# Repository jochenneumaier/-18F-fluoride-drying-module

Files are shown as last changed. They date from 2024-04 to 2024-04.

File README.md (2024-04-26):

# 18F-fluoride-drying-module
Automated drying module for [18F]fluoride

One of the key strategies for radiochemical research facilities is the automation of synthesis processes. Unnecessary manual operations increase the radiation exposure of personnel, while simultaneously threatening the reliability of syntheses. We have previously reported an affordable open-source system comprising 3D-printed continuous flow reactors, a custom syringe pump, and a pressure regulator that can be used to perform radiofluorinations. In this paper, we address additional essential processes which are needed for radiotracer development and synthesis, with the aim of making laboratory work safer and research more efficient. We have designed and evaluated a fully automated system for rapidly and effectively processing and drying aqueous [18F]fluoride that can be directly connected to the cyclotron. This process relies on triflyl fluoride gas generation and allows nucleophilic [18F]fluoride to be prepared safely in a hotcell within 10 minutes and an activity recovery of 91.7 ± 1.6% (n=5). Owing to the need for convenient radiofluorinated prosthetic ligands, we have adapted our continuous flow system to produce [18F]fluoroethyl tosylate (FEOTs) and [18F]fluoroethyl triflate (FEOTf), prosthetic groups that are widely used for late-stage fluoroethylation of PET tracers. The processes as well as the radiolabeling of different groups are compared and comprehensively discussed. Having a method providing [18F]fluoroethyl tosylate (FEOTs) as well as [18F]fluoroethyl triflate (FEOTf) quickly and highly efficiently is beneficial for radiochemical research. 

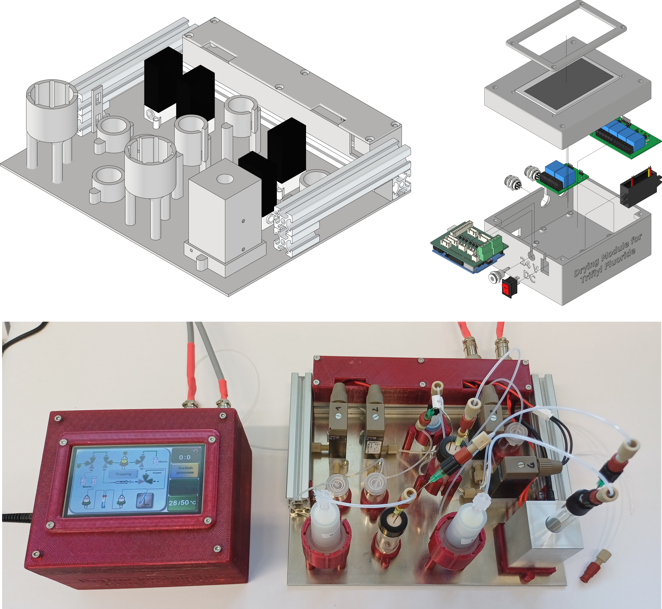
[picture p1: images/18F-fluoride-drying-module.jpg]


The work was published in the Journal of Labelled Compounds and Radiopharmaceuticals:

Open-source flow setup for rapid and efficient [18F]fluoride drying for automation of PET tracer syntheses, F. Menzel, J. Cotton, T. Ziegler, A. Maurer, J. M. Neumaier, J. Label. Compd. Radiopharm. 2023, 1-19, 

https://doi.org/10.1002/jlcr.4080

https://analyticalsciencejournals.onlinelibrary.wiley.com/doi/epdf/10.1002/jlcr.4080

A detailed assembly instructions can also be downloaded here:

https://analyticalsciencejournals.onlinelibrary.wiley.com/action/downloadSupplement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

All CAD and stl files as well as the Arduino and Nextion program codes can be downloaded here:

https://analyticalsciencejournals.onlinelibrary.wiley.com/action/downloadSupplement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

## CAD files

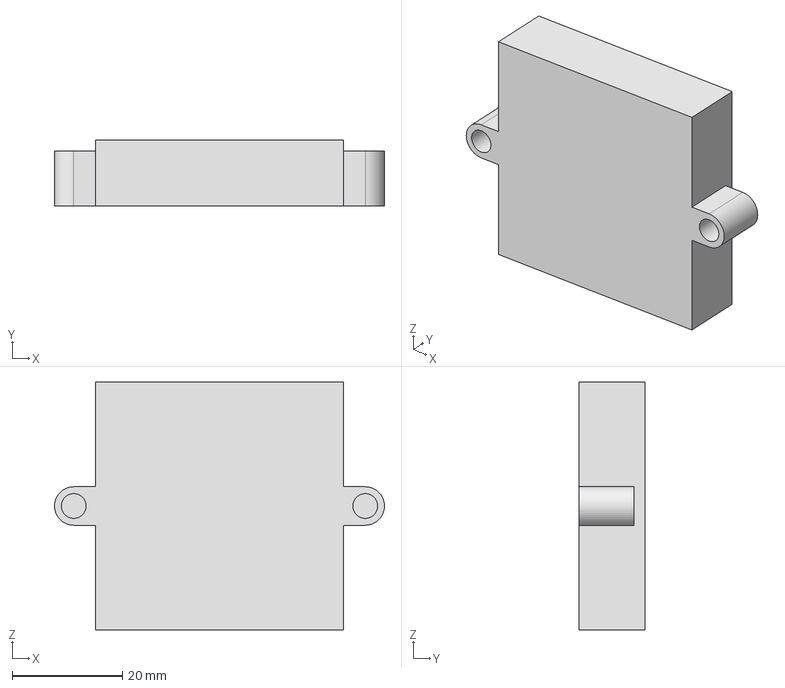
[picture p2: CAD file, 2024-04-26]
CAD files/5 - Holder heating block.stp
60.0 x 12.0 x 45.0 mm

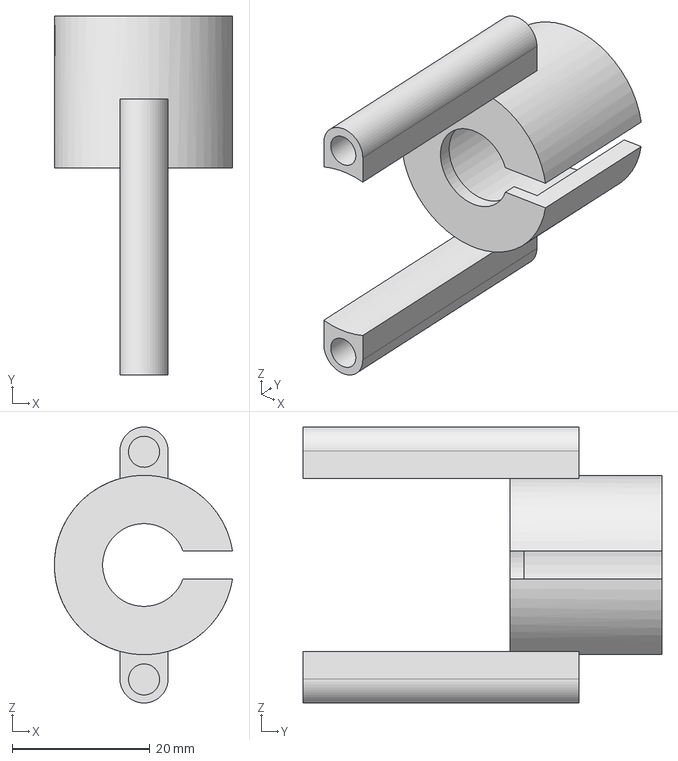
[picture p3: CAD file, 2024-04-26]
CAD files/1 - Holder QMA.stp
25.8 x 52.0 x 40.0 mm

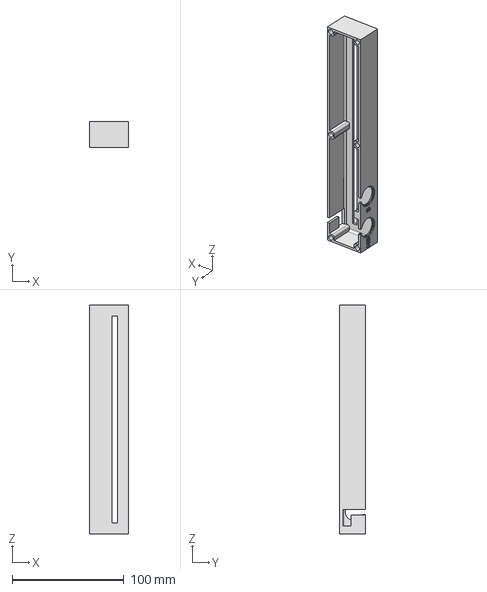
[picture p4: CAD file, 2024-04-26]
CAD files/6 - Cable box.stp
35.0 x 23.0 x 205.0 mm

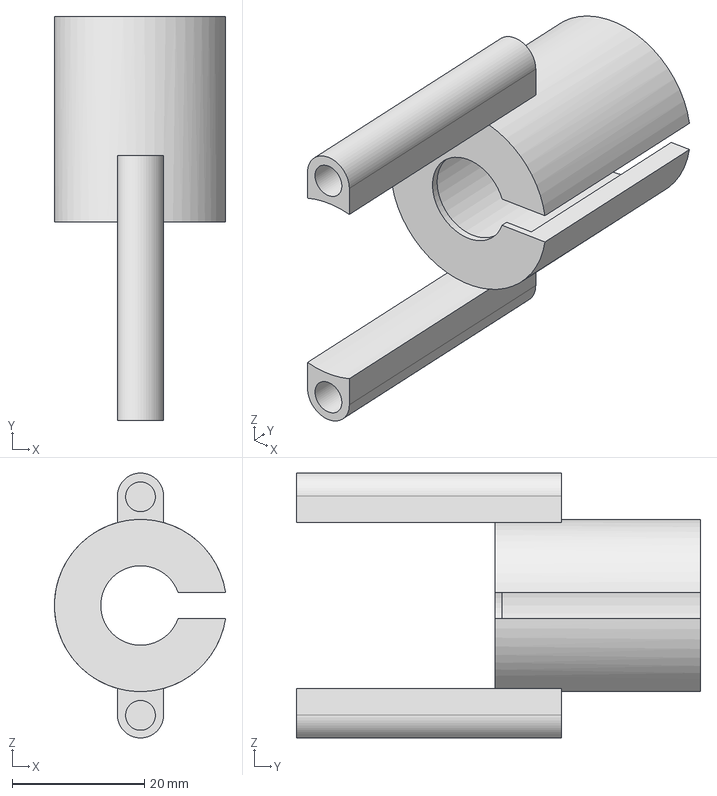
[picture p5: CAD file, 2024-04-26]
CAD files/2 - Holder v-vial, high.stp
25.8 x 61.0 x 40.0 mm

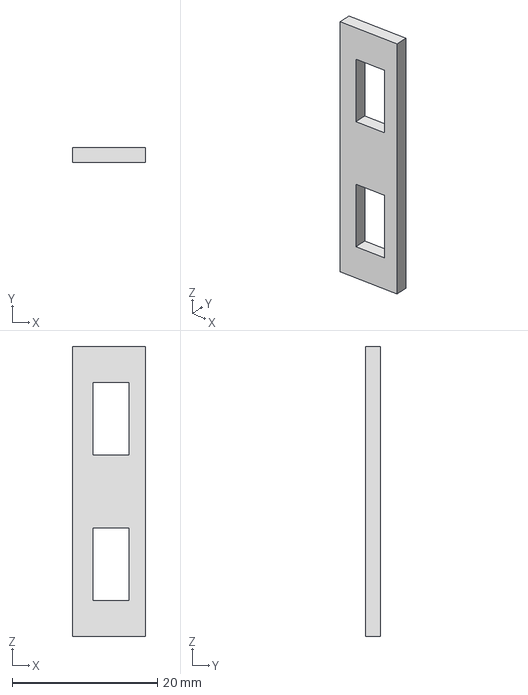
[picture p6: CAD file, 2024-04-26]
CAD files/8 - Profile connector straight.stp
10.0 x 2.00 x 40.0 mm

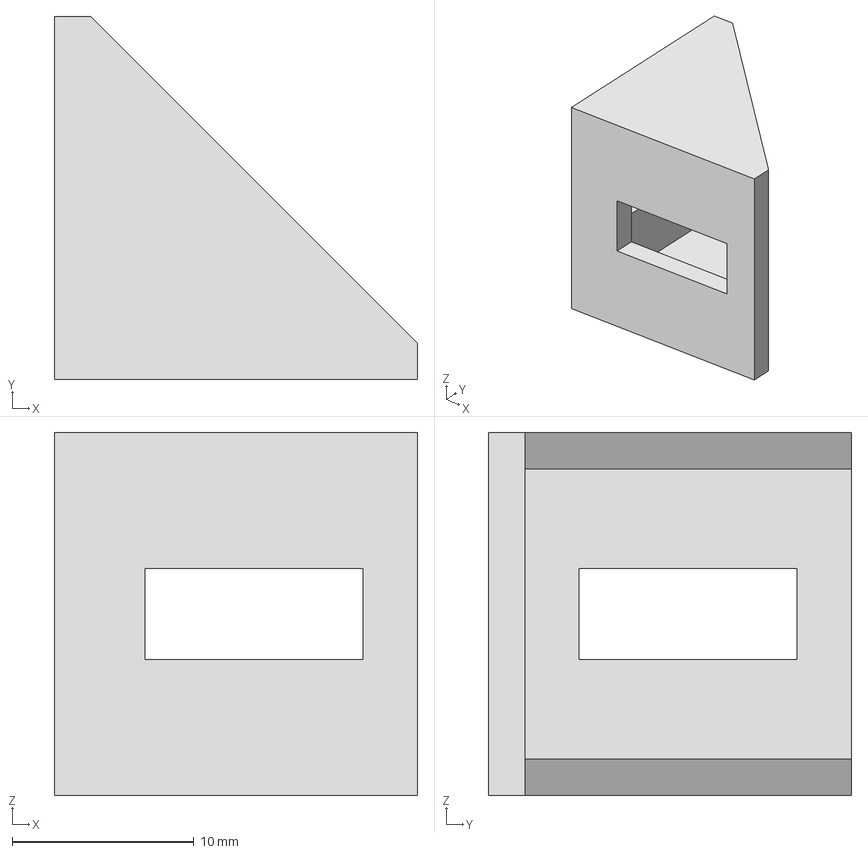
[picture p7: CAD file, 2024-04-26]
CAD files/9 - Profile connector 90 degree.stp
20.0 x 20.0 x 20.0 mm

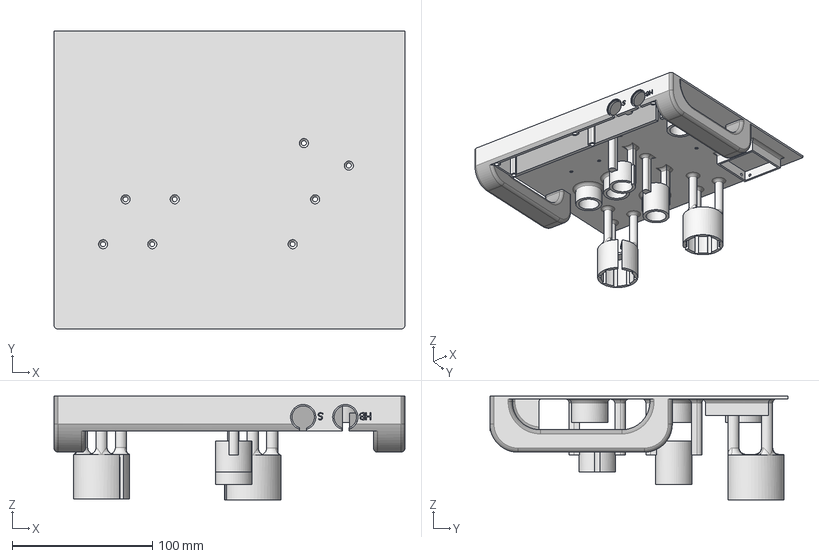
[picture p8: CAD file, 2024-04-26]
CAD files/50 - All-in-one base plate.stp
250.0 x 212.5 x 74.0 mm

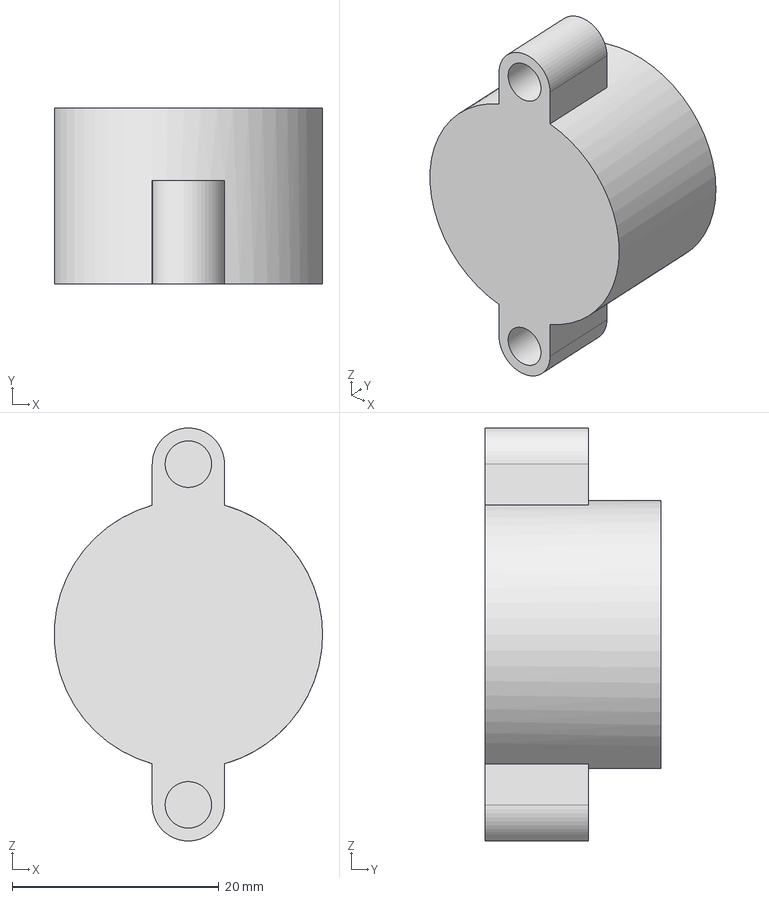
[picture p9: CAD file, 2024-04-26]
CAD files/3 - Holder waste, v-vial low.stp
26.0 x 17.0 x 40.0 mm

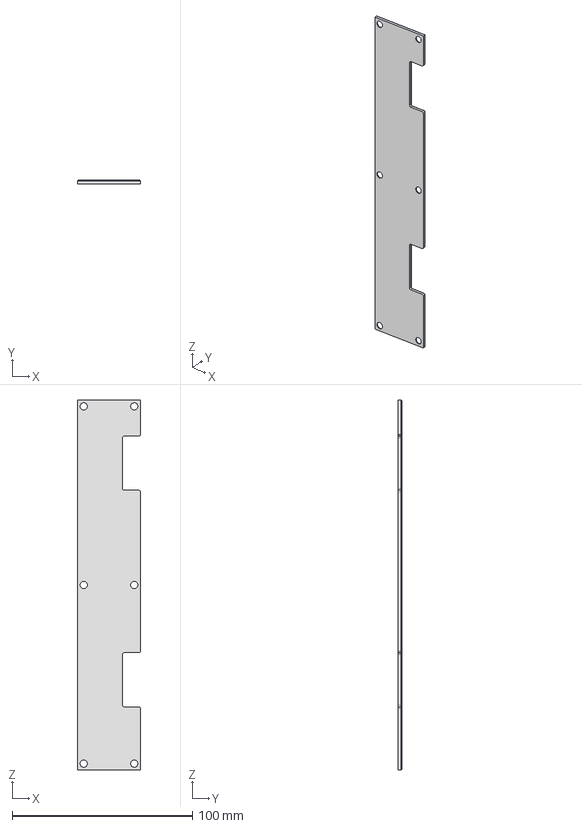
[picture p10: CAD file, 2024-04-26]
CAD files/7 - Cable box lid.stp
35.0 x 2.00 x 205.0 mm

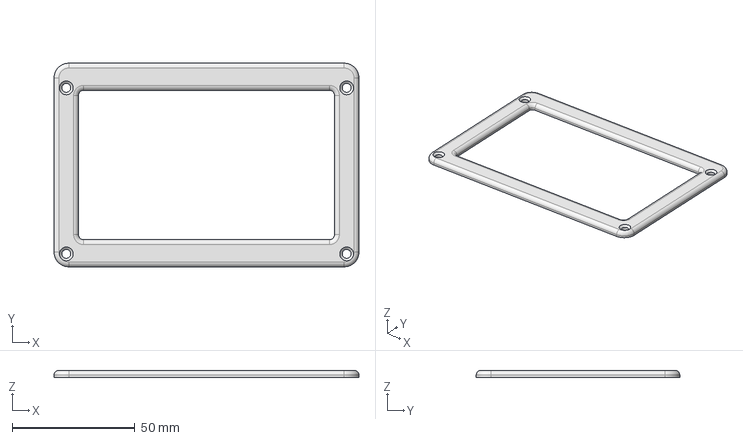
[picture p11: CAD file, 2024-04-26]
CAD files/17 - Display frame.stp
124.0 x 82.8 x 3.00 mm

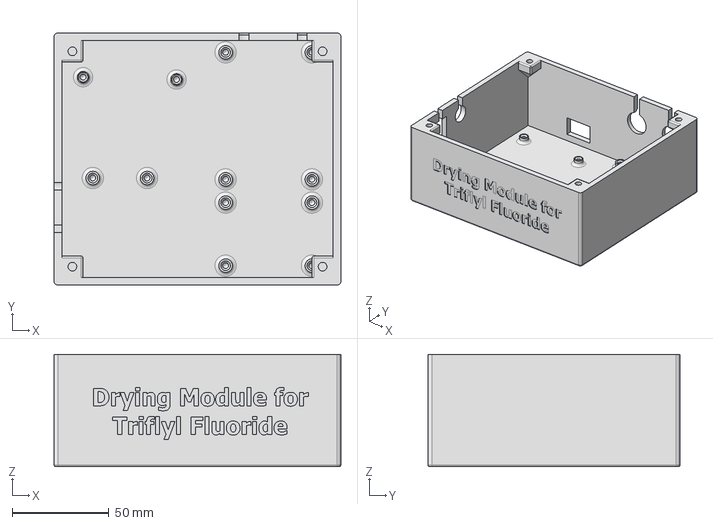
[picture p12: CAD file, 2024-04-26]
CAD files/15 - Case control unit.stp
148.0 x 130.0 x 58.0 mm

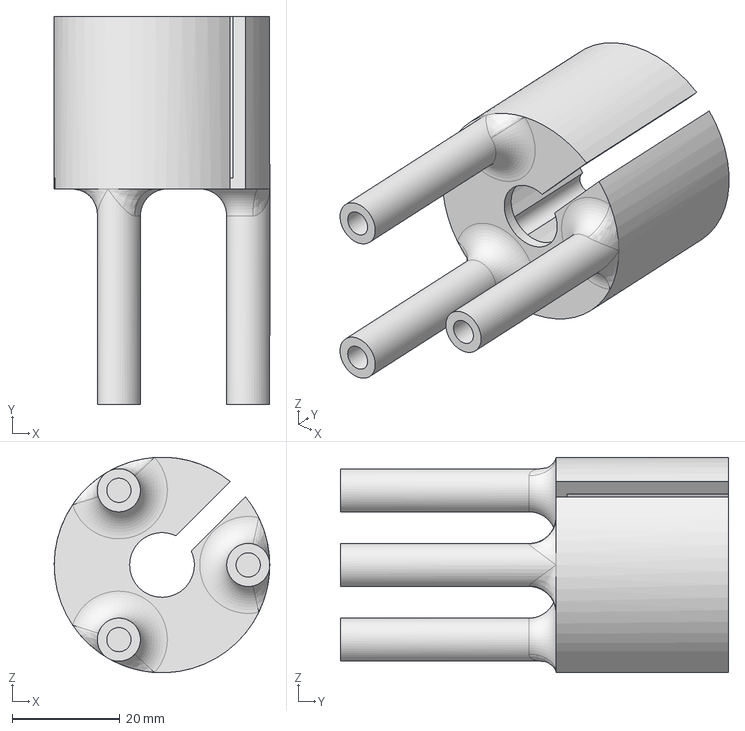
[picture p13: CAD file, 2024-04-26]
CAD files/4 - Holder cartridge.stp
40.0 x 72.0 x 40.0 mm

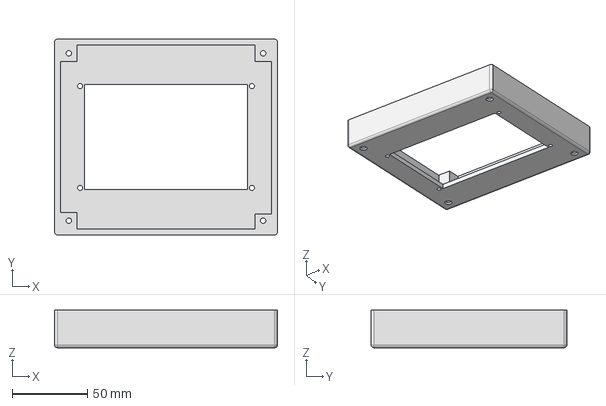
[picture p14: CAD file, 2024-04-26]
CAD files/16 - Case lid.stp
148.0 x 130.0 x 25.0 mm

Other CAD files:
CAD files/1 - Holder QMA.stl
CAD files/15 - Case control unit.stl
CAD files/16 - Case lid.stl
CAD files/17 - Display frame.stl
CAD files/2 - Holder v-vial, high.stl
CAD files/3 - Holder waste, v-vial low.stl
CAD files/4 - Holder cartridge.stl
CAD files/5 - Holder heating block.stl
CAD files/50 - All-in-one base plate.stl
CAD files/6 - Cable box.stl
CAD files/7 - Cable box lid.stl
CAD files/8 - Profile connector straight.stl
CAD files/9 - Profile connector 90 degree.stl

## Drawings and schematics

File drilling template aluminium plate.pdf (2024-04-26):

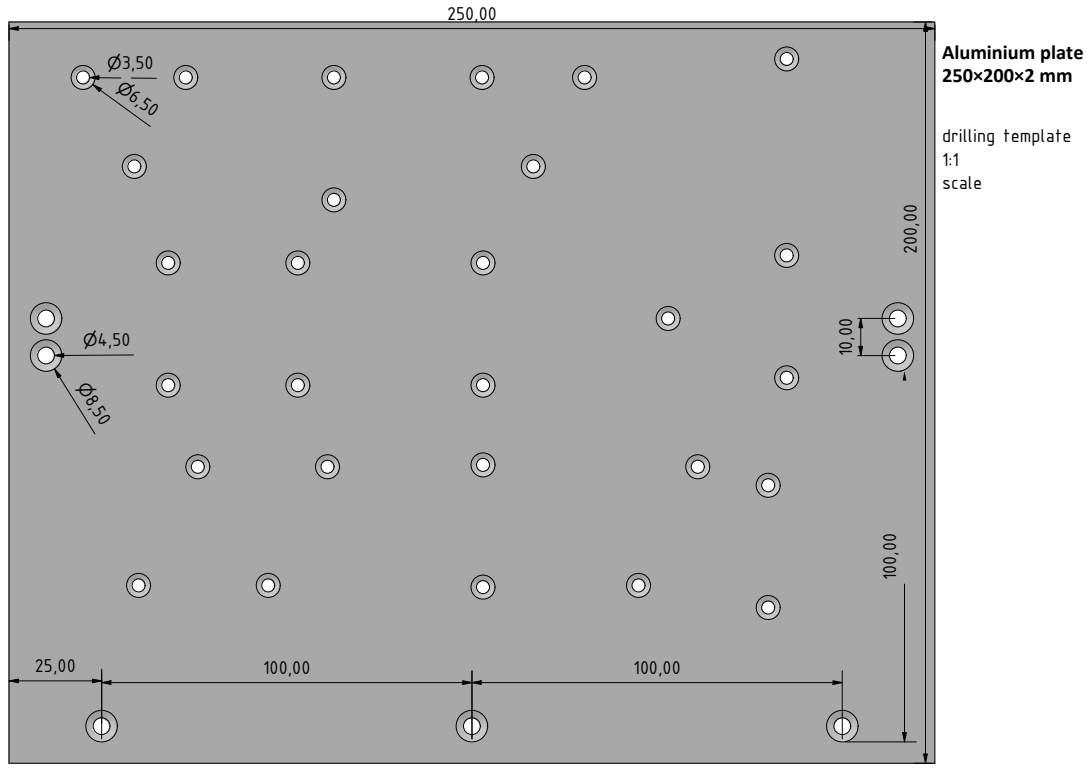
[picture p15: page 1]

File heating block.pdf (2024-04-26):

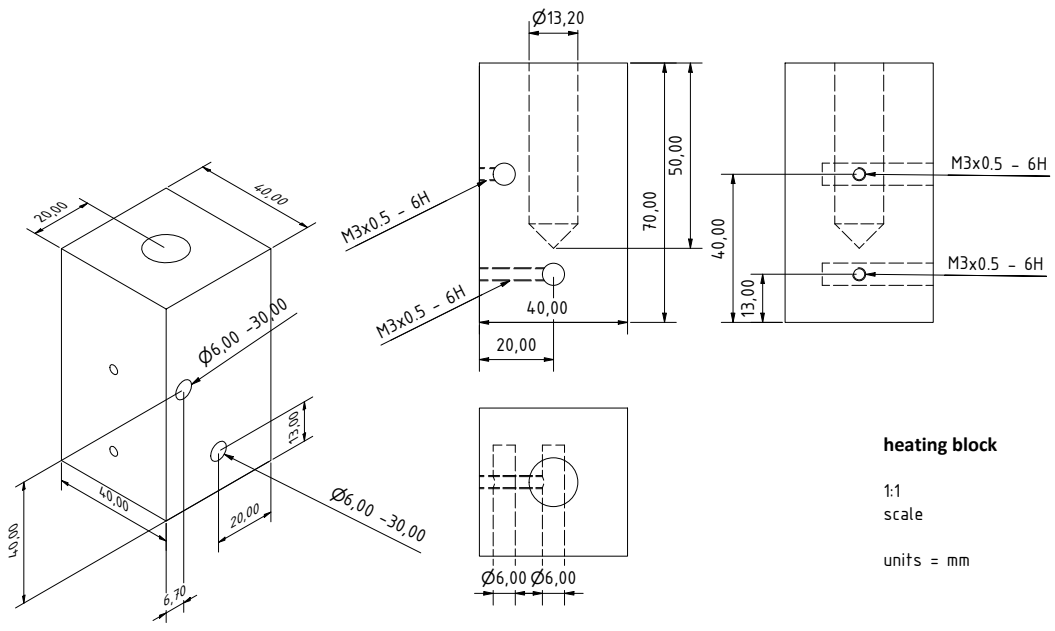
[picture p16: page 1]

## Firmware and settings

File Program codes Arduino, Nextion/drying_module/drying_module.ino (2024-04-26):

#include <Nextion.h>          // not included in the library manager, have to be downloaded manually:  https://github.com/bborncr/nextion
#include <SoftwareSerial.h>   // Software Serial Port (included in Arduino IDE "no download")
#include <OneWire.h>          // V 2.3.7 used, included in the library manager, see also: https://www.pjrc.com/teensy/td_libs_OneWire.html
#include <DallasTemperature.h>  //V3.9.0 used, included in the library manager, see also: https://github.com/milesburton/Arduino-Temperature-Control-Library
SoftwareSerial nextion(2, 3);// Nextion (TX, RX) via software serial
Nextion myNextion(nextion, 9600); // Setup of Nextion library with name NextionLCD at 9600bps

#define ONE_WIRE_BUS 10 //Data from Temp Sensor
OneWire oneWire (ONE_WIRE_BUS);
DallasTemperature sensors(&oneWire);
float temp = 0;
unsigned long sendtemp = 0;
int settemp = 20;
byte heating = 0;
#define heating1 8
#define valve1 4
#define valve2 5
#define valve3 6
#define valve4 7
#define heating1 8
#define heating2 9

byte tempmenu = 0;
byte dryingstatus = 0;

String message;   // received message for Nextion LCD

void setup()
{
  pinMode(valve1, OUTPUT);
  pinMode(valve2, OUTPUT);
  pinMode(valve3, OUTPUT);
  pinMode(valve4, OUTPUT);
  pinMode(heating1, OUTPUT);
  pinMode(heating2, OUTPUT);

  digitalWrite(valve1, HIGH); // 0V
  digitalWrite(valve2, HIGH); // 0V
  digitalWrite(valve3, HIGH); // 0V
  digitalWrite(valve4, HIGH); // 0V
  digitalWrite(heating1, HIGH); //0V
  digitalWrite(heating2, HIGH); //0V

  myNextion.init();
  nextion.begin(9600); // open the software serial port at 9600 bps:
  sensors.begin();
}

void loop() {

  //------------------------------------------------------------------------------------------
  //  buttons action
  //------------------------------------------------------------------------------------------

  message = myNextion.listen(); //check for message
  if (message != "") { // if a message is received...

    //---------------switch valve 1-----------------

    if (message == "65 2 2 1 ffff ffff ffff") {
      digitalWrite(valve1, LOW); // 5V
      delay (200);
      myNextion.setComponentValue("custom.valve1state", 1);
      myNextion.sendCommand("vis valve1nc,1");
    }
    if (message == "65 2 8 1 ffff ffff ffff") {
      digitalWrite(valve1, HIGH); // 0V
      delay (200);
      myNextion.setComponentValue("custom.valve1state", 0);
      myNextion.sendCommand("vis valve1nc,0");
    }

    //---------------switch valve 2-----------------
    if (message == "65 2 3 1 ffff ffff ffff") {
      digitalWrite(valve2, LOW); // 5V
      delay (200);
      myNextion.setComponentValue("custom.valve2state", 1);
      myNextion.sendCommand("vis valve2nc,1");
    }
    if (message == "65 2 9 1 ffff ffff ffff") {
      digitalWrite(valve2, HIGH); // 5V
      delay (200);
      myNextion.setComponentValue("custom.valve2state", 0);
      myNextion.sendCommand("vis valve2nc,0");
    }

    //---------------switch valve 3-----------------

    if (message == "65 2 c 1 ffff ffff ffff") {
      digitalWrite(valve3, LOW); // 5V
      delay (200);
      myNextion.setComponentValue("custom.valve3state", 1);
      myNextion.sendCommand("vis valve3nc,1");
    }
    if (message == "65 2 e 1 ffff ffff ffff") {
      digitalWrite(valve3, HIGH); // 0V
      delay (200);
      myNextion.setComponentValue("custom.valve3state", 0);
      myNextion.sendCommand("vis valve3nc,0");
    }

    //---------------switch valve 4-----------------

    if (message == "65 2 d 1 ffff ffff ffff") {
      digitalWrite(valve4, LOW); // 5V
      delay (200);
      myNextion.setComponentValue("custom.valve4state", 1);
      myNextion.sendCommand("vis valve4nc,1");
    }
    if (message == "65 2 f 1 ffff ffff ffff") {
      digitalWrite(valve4, HIGH); // 0V
      delay (200);
      myNextion.setComponentValue("custom.valve4state", 0);
      myNextion.sendCommand("vis valve4nc,0");
    }

    //---------------drying mode start conditions-----------------

    if (message == "65 0 1 1 ffff ffff ffff") {
      digitalWrite(valve1, LOW); // 5V
      digitalWrite(valve2, HIGH); // 0V
      digitalWrite(valve3, LOW); // 5V
      digitalWrite(valve4, LOW); // 5V
      delay (200);
    }

    //---------------drying mode switch button-----------------

    if (message == "65 1 5 1 ffff ffff ffff") {
      if (dryingstatus == 0) {
        digitalWrite(valve1, HIGH);
        digitalWrite(valve2, LOW);
        digitalWrite(valve3, HIGH);
        digitalWrite(valve4, HIGH);
        delay (200);
        dryingstatus = 1;
        myNextion.setComponentValue("drying.valvedrystate", 1);
        myNextion.sendCommand("vis q3,1");
      }
      else {
        digitalWrite(valve1, LOW); // 5V
        digitalWrite(valve2, HIGH); // 0V
        digitalWrite(valve3, LOW); // 5V
        digitalWrite(valve4, LOW); // 5V
        delay (200);
        dryingstatus = 0;
        myNextion.setComponentValue("drying.valvedrystate", 0);
        myNextion.sendCommand("vis q3,0");
      }
    }
    //------------ set Temp menu ----------------

    if ((message == "65 1 6 1 ffff ffff ffff") || (message == "65 2 4 1 ffff ffff ffff")) {    //drying temp
      tempmenu = 1;
    }

    do {
      message = myNextion.listen(); //check for message
      if (message == "65 3 2 1 ffff ffff ffff") {
        tempmenu = 0;
        sendtemp = 0;
        delay(200);
        settemp = myNextion.getComponentValue("temp.settemp");
        myNextion.setComponentText("drying.t2", String(settemp));
        myNextion.setComponentText("custom.t1", String(settemp));
      }
      if (message == "65 3 1 1 ffff ffff ffff") {
        tempmenu = 0;
        sendtemp = 0;
      }
    } while (tempmenu == 1);

  } //message

  // -------------- send Temp to Nextion from Sensor (in a text field)-------------------

  if (millis() - sendtemp >= 1000) {
    sendtemp = millis();
    sensors.requestTemperatures();
    temp = sensors.getTempCByIndex(0);
    nextion.print("custom.temp.txt=\"");
    nextion.print(temp, 1);         // 1 decimal place
    nextion.print("\"");
    nextion.write(0xff);
    nextion.write(0xff);
    nextion.write(0xff);
    nextion.print("drying.t1.txt=\"");
    nextion.print(temp, 0);         // 0 decimal place
    nextion.print("\"");
    nextion.write(0xff);
    nextion.write(0xff);
    nextion.write(0xff);
  }

  // -------------- heating-------------------

  if (temp < (settemp - 1)) {
    heating = 1;
  }
  if (temp > (settemp - 1)) {
    heating = 0;
  }
  if (heating == 1) {
    digitalWrite(heating1, LOW);  //LOW = heating on
  }
  if (heating == 0) {
    digitalWrite(heating1, HIGH);  //HIGH = heating off
  }
} // loop
